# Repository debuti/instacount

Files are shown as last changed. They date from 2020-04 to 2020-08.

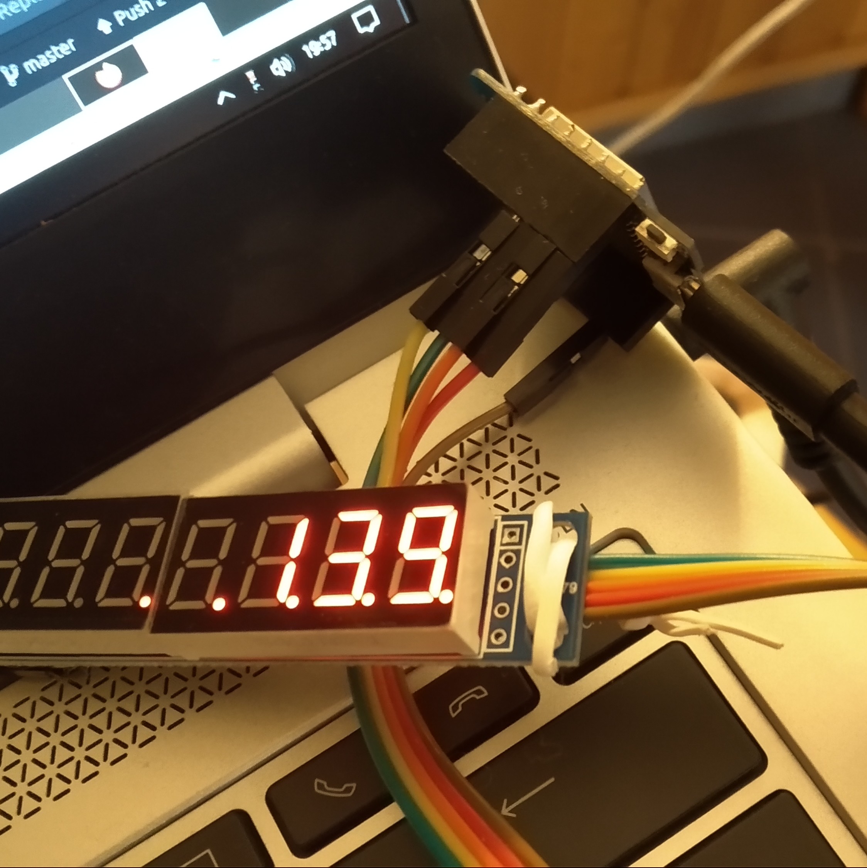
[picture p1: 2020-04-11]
IMG_20200409_195725.jpg

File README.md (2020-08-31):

# instacount

Sketch and hardware solution to display the followers count for any user

## Quick start
 * Connect to _instacount_ hotspot -> A captive portal for configuration will open
 * Insert your wifi details, the target Instagram account and your Instagram credentials. Adjust the other parameters to taste
 * Once saved the device will try to connect to the wifi network, if successful it will try to fetch the followers count using one of the provided Instagram credentials, if successful you are good to go, if not ..
 
## Troubleshooting
 * The device doesnt show anything on the display
   * Sometimes these chinese displays are unresponsive. Unplug and replug several times until the digits light up
 * The device never goes out of config
   * The wifi credentials are not correct, recheck them
 * The device always shows 0 followers
   * The Instagram credentials are not correct, recheck them. 
   * Try to use those credentials in a browser to see if they are challenged or banned by Instagram
 * The device shows 0 followers when powered-up
   * I'm working on this
 * When I reconfigure the device, the Instagram credentials are not persisted
   * They are, but they are not showed for security reasons! If the module is set to config mode without you knowing it, and your neighbour connects to the config page s/he will see your plain text password

## Description and usage
Polling updated display to show the count of followers of a given Instagram account.

Sadly, Instagram has no public API to retrieve the followers count for a given user. Because of that, instacount uses web scrapping methods to retrieve this information. Although it works, it is not the best solution as Instagram controls the number of requests made to its servers and can deny the access to resources for a given user. As of April 2020 the quota is 500 requests/user*day, meaning that a request can be made each 2.88 minutes

To overcome this limitation, instacount uses two concepts combined:
 * Poll more often at daytime and less often at night.
 * Use several accounts to be able to make requests as quick as possible.

Last, Instagram handles suspicious activities by issuing a challenge. If a given account is challenged, it wont be able to login and thus retrieve the count. To overcome this just login to the account from a web browser and response to the challenge. As instacount wont warn about this, to detect and be able to solve this, it is best to use your own accounts with instacount (and not dummy accounts)

## Features
 * Login based approach to enable a multi-account strategy
 * Configurable via wifi captive portal
 * Countdown until next request shown via display dots
 * Smart cooldown mechanism to temporarily disable the accounts that got too many requests
 * .dxf for case routing/printing also included!

## Hardware design
### BOM
 * ESP12E board
 * MAX7219 8-digit 8-segments module
 * Breakout board for ESP12E
 * 3,3V voltage regulator (remove the 0 Ohm resistor from the breakout board!)

### Connections
```
ESP12E GPIO13 to MAX7219 CLK
ESP12E GPIO12 to MAX7219 CS
ESP12E GPIO14 to MAX7219 DIN
```

## Build environment
 * PlatformIO: Quick-install with this *nosudo* oneliner `python3 -c "$(curl -fsSL https://raw.githubusercontent.com/platformio/platformio/develop/scripts/get-platformio.py)"; export PATH=$PATH:~/.platformio/penv/bin`

## Libraries
 * WifiManager
 * LedControl
 * DoubleResetDetector
 * ArduinoJSON

## Building
 * Go to the project folder and type `pio run` to build
 * Or `pio run -t upload` to upload

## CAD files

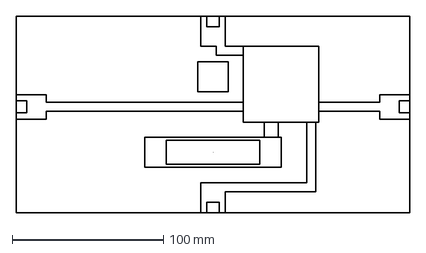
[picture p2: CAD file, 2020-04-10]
cam/instacount-panel-a.dxf
260.0 x 130.0 mm

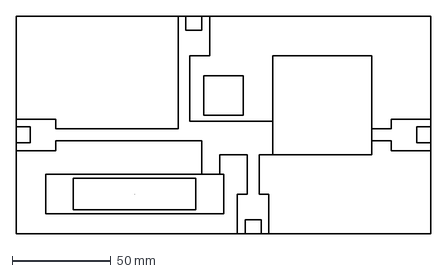
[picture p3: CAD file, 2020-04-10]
cam/instacount-panel-b.dxf
210.0 x 110.0 mm

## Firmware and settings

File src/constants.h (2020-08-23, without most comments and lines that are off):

#define DEBUG    true
#define LOG(str) if (DEBUG) Serial.println(str);
#define XSTR(s)	 STR(s)
#define STR(s)	 #s
#define DISPLAY_CLK						14
#define DISPLAY_LOAD					12
#define DISPLAY_DATA_IN				13
#define MAX7219_COUNT					1
#define DRD_TIMEOUT 					5						// Number of seconds after reset during which a subseqent reset will be considered a double reset. This sketch uses drd.stop() rather than relying on the timeout
#define DRD_ADDRESS						0						// RTC Memory Address for the DoubleResetDetector to use
#define INSTA_SCHEMA					"https://"
#define INSTA_HOST						"www.instagram.com"
#define BASE_PATH						  "/"
#define LOGIN_PATH						"/accounts/login/ajax/"
#define INSTA_PORT						443
#define INSTA_API_POSTFIX			"/?__a=1"
#define MAX_REQUESTS_DAY_PER_ACCOUNT	500
#define CHROME_WIN_UA 				"Mozilla/5.0 (Windows NT 10.0; WOW64) AppleWebKit/537.36 (KHTML, like Gecko) Chrome/67.0.3396.87 Safari/537.36"
#define STORIES_UA						"Instagram 123.0.0.21.114 (iPhone; CPU iPhone OS 11_4 like Mac OS X; en_US; en-US; scale=2.00; 750x1334) AppleWebKit/605.1.15"
#define COOLDOWN_MIN  				6*60*60*1000
#define COOLDOWN_INC  				3
#define DEFAULT_AP						"instacount"
#define DEFAULT_NIGHT_START		0
#define DEFAULT_NIGHT_END			8
#define DEFAULT_NIGHT_SPACING	3600
#define HTML_CSS_STYLES \
"<style>" \
".alert {" \
"  margin: 10px;" \
"  padding: 20px;" \
"  opacity: 1;" \
"  transition: opacity 0.6s;" \
"  margin-bottom: 15px;" \
"  font-family: -apple-system,BlinkMacSystemFont,\"Segoe UI\",Roboto,\"Helvetica Neue\",Arial,sans-serif,\"Apple Color Emoji\",\"Segoe UI Emoji\",\"Segoe UI Symbol\";" \
"  box-sizing: border-box;" \
"  border: 1px solid transparent;" \
"  border-radius: .25rem;" \
"  line-height: 1.5;" \
"}" \
".alert.info {" \
"  color: #004085;" \
"  background-color: #cce5ff;" \
"  border-color: #b8daff;" \
"}" \
".alert.light {" \
"  color: #818182;" \
"  background-color: #fefefe;" \
"  border-color: #fdfdfe;" \
"  margin: 2px;" \
"  padding: 2px;" \
"}" \
"</style>"
#define HTML_GLOBAL_HELP \
"<div class=\"alert info\">" \
"  <strong>Instacount instructions</strong>" \
"  <p>The configuration of instacount is made through a captive wifi portal. At first, since no configuration is yet made, instacount will expose the captive portal by default. Just connect to it and modify the parameters to fit your needs. If at some point you want to reconfigure instacount, just press the reset button twice, and the captive portal will show up again. Whenever the led stays on for 10 seconds or so after boot, and -conFiG- is shown in the display, the config portal will be on. Mind that if the configuration cannot be applied the captive portal will show up again.</p>" \
"  <p>Sadly, Instagram has no public API to retrieve the followers count for a given user. Because of that, instacount uses web scrapping methods to retrieve this information. Although it works, it is not the best solution as Instagram controls the number of requests made to its servers and can deny the access to resources for a given user. As of April 2020 the quota is 500 requests/user*day, meaning that a request can be made each 2.88 minutes</p>" \
"  <p>To overcome this limitation, instacount uses two concepts combined:" \
"    <ul>" \
"    <li>Poll more often at daytime and less often at night.</li>" \
"    <li>Use several accounts to be able to make requests as quick as possible.</li>" \
"    </ul>" \
"  </p>" \
"  <p>The display dots will be lightened in order to show the amount of time left until the next request.</p>" \
"  <p>Last, Instagram handles suspicious activities by issuing a challenge. If a given account is challenged, it wont be able to login and thus retrieve the count. To overcome this just login to the account from a web browser and response to the challenge. As instacount wont warn about this, to detect and be able to solve this, it is best to use your own accounts with instacount (and not dummy accounts)</p>" \
"</div>"
#define HTML_PROFILE_HELP\
"<div class=\"alert light\">" \
"  Insert the Instagram profile to be polled for followers count" \
"</div>"
#define HTML_ACCOUNTS_HELP\
"<div class=\"alert light\">" \
"  Insert at least one account/password. The format is: <br>" \
"  user1:passwd1;user2:passwd2;...<br>" \
"  Previously introduced credentials are not shown for security reasons. The field is limited to 100 characters." \
"</div>"
#define HTML_NIGHT_HELP\
"<div class=\"alert light\">" \
"  Insert the start and finish hours for the night, and the number of seconds you want instacount to wait between requests. <br>" \
"  Remember, the less usage at night means the more at day!" \
"</div>"
#define HTML_REQUESTS_HELP\
"<div class=\"alert light\">" \
"  This should be set to "XSTR(MAX_REQUESTS_DAY_PER_ACCOUNT)" but if you suffer a lot of cooldowns you'll probably need to decrease this value" \
"</div>"
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

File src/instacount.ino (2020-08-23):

#include "constants.h"

#include <ESP8266WiFi.h>
#include <WiFiClientSecure.h>
// Additional libraries needed by WiFiManager
#include <DNSServer.h>
//Local DNS Server used for redirecting all rs to the configuration portal
#include <ESP8266WebServer.h>
//Local WebServer used to serve the configuration portal


// To use this sketch in an ESP8266 board you have to follow the instructions at
// https://github.com/esp8266/Arduino#installing-with-boards-manager


#include <LedControl.h>
// To control an MAX7219 enabled display
// https://github.com/debuti/LedControl
// More advanced library based on wayoda's LedControl
// https://github.com/wayoda/LedControl

#include <DoubleResetDetector.h>
// For entering Config mode by pressing reset twice
// Available on the library manager (DoubleResetDetector)
// https://github.com/datacute/DoubleResetDetector

#include <ArduinoJson.h>
// Required for the YouTubeApi and used for the config file
// Available on the library manager (ArduinoJson)
// https://github.com/bblanchon/ArduinoJson

#include <WiFiManager.h>
// For configuring the Wifi credentials without re-programing
// Availalbe on library manager (WiFiManager)
// https://github.com/tzapu/WiFiManager

#include "FS.h"
// For storing configurations
// Already included in the include path by the esp8266 core
// https://arduino-esp8266.readthedocs.io/en/latest/filesystem.html


/** Typedefs **/
typedef struct {
  char* k;
  char* v;
} cookie_t;

typedef struct {
  char*         usr;
  char*         pwd;
  uint8_t       cookies_nb;
  cookie_t**    cookies;
  char*         csrftoken;
  unsigned long cooldown_until;
  unsigned long lasttry;
  unsigned long logins_nb;
  unsigned long ok_nb;
  unsigned long ko_nb;
} account_t;

typedef struct {
  uint8_t     start;
  uint8_t     end;
  uint16_t    spacing;
} night_t;

typedef struct {
  char*         profile;
  unsigned long max_requests_day_per_account;
  night_t       night;
  night_t       day;
  uint8_t       accounts_nb;
  account_t**   accounts;
} config_t;


/** Globals **/
WiFiClientSecure client;
DoubleResetDetector drd(DRD_TIMEOUT, DRD_ADDRESS);
LedControl lc = LedControl(DISPLAY_DATA_IN, DISPLAY_CLK, DISPLAY_LOAD, MAX7219_COUNT);

char ap[] = DEFAULT_AP;

const unsigned char caCert[] PROGMEM = DIGICERT_SHA2_HIGH_ASSURANCE_SERVER_CA;
const unsigned int caCertLen = (sizeof(caCert) / sizeof(caCert[0]));
const char* host PROGMEM = INSTA_HOST;
const int httpsPort = INSTA_PORT;
const char url_postfix[] PROGMEM = INSTA_API_POSTFIX;

bool shouldSaveConfig  = false;                         // flag for saving data
bool enteredConfigMode = false;                         // flag for state machine

unsigned long api_lasttime = 0;                         //last time api request has been done

config_t config = {
  .profile                      = NULL,
  .max_requests_day_per_account = MAX_REQUESTS_DAY_PER_ACCOUNT,
  .night = {
    .start                      = DEFAULT_NIGHT_START,
    .end                        = DEFAULT_NIGHT_END,
    .spacing                    = DEFAULT_NIGHT_SPACING
  },
  .day = {
    .start                      = DEFAULT_NIGHT_END,
    .end                        = DEFAULT_NIGHT_START,
    .spacing                    = 0
  },
  .accounts_nb                  = 0,
  .accounts                     = NULL
};



void printConfig(config_t* config) {
  Serial.println("config {");
  Serial.print("  profile : ");Serial.println(config->profile);
  Serial.print("  maxreqs : ");Serial.println(config->max_requests_day_per_account);
  Serial.println("  \t\tstart\tend\tspacing");
  Serial.print("  night :\t");Serial.print(config->night.start);Serial.print("\t");Serial.print(config->night.end);Serial.print("\t");Serial.println(config->night.spacing);
  Serial.print("  day :\t\t");Serial.print(config->day.start);Serial.print("\t");Serial.print(config->day.end);Serial.print("\t");Serial.println(config->day.spacing);
  Serial.print("  accounts[");Serial.print(config->accounts_nb);Serial.println("] {");
  for (int i=0; i<config->accounts_nb; i++) {
    Serial.println("    account {");
    {
      Serial.print("      usr/pwd :\t\t");Serial.print(config->accounts[i]->usr);Serial.print(":");
      for (int j=0; j<strlen(config->accounts[i]->pwd); j++) Serial.print('*');
      Serial.println();
    }
    Serial.print("      cool :\t\t");Serial.println(config->accounts[i]->cooldown_until);
    Serial.print("      lasttry :\t\t");Serial.println(config->accounts[i]->lasttry);
    {
      Serial.println("      logins_nb\tko_nb\tok_nb");
      Serial.print("      ");Serial.print(config->accounts[i]->logins_nb); Serial.print("\t\t");Serial.print(config->accounts[i]->ko_nb);Serial.print("\t");Serial.println(config->accounts[i]->ok_nb);
    }
    Serial.print("      csrftoken :\t");Serial.println((config->accounts[i]->csrftoken?config->accounts[i]->csrftoken:"NULL"));
    Serial.print("      cookies[");Serial.print(config->accounts[i]->cookies_nb);Serial.println("] {");
    for (int j=0; j<config->accounts[i]->cookies_nb; j++) {
      Serial.print("        ");Serial.print(config->accounts[i]->cookies[j]->k);Serial.print( " : ");Serial.println(config->accounts[i]->cookies[j]->v);
    }
    Serial.println("      }");
    Serial.println("    }");
  }
  Serial.println("  }");
  Serial.println("}");
}

/**
 * Frees the memory associated to the dynamic object
 **/
bool freeConfig(config_t* config) {
  free(config->profile);
  for (int idx = 0; idx < config->accounts_nb; idx++) {
    free(config->accounts[idx]->usr);
    free(config->accounts[idx]->pwd);
    free(config->accounts[idx]->csrftoken);
    for (int j=0; j<config->accounts[idx]->cookies_nb; j++) {
      free(config->accounts[idx]->cookies[j]->k);
      free(config->accounts[idx]->cookies[j]->v);
      free(config->accounts[idx]->cookies[j]);
    }
    free(config->accounts[idx]);
  }
  free(config->accounts);
}

/**
 * Checks if the config makes sense
 **/
bool checkConfig(config_t* config) {
  return ((strcmp(config->profile, "") > 0) && \
          (config->accounts_nb > 0) && \
          (config->accounts != NULL));
}

/**
 * Loads the configuration from storaged JSON into dynamic object
 **/
bool loadConfig(config_t* config) {
  File configFile = SPIFFS.open("/config.json", "r");
  if (!configFile) {
    Serial.println("Failed to open config file");
    return false;
  }

  size_t size = configFile.size();
  if (size > 1024) {
    Serial.println("Config file size is too large");
    return false;
  }

  StaticJsonDocument<500> json;
  DeserializationError err = deserializeJson(json, configFile);
  if (err) {
    Serial.println("Failed to parse config file");
    return false;
  }

  if (json["profile"]) config->profile = strdup(json["profile"]);
  if (json["max_requests_day_per_account"]) config->max_requests_day_per_account = json["max_requests_day_per_account"];
  if (json["accounts"]) {
    config->accounts = (account_t**)malloc(sizeof(account_t*)*json["accounts"].size());
    for (int idx = 0; idx < json["accounts"].size(); idx++) {
      config->accounts[idx] = (account_t*)malloc(sizeof(account_t));
      config->accounts[idx]->usr = strdup(json["accounts"][idx]["usr"]);
      config->accounts[idx]->pwd = strdup(json["accounts"][idx]["pwd"]);
      config->accounts[idx]->cookies_nb = 0;
      config->accounts[idx]->cookies = NULL;
      config->accounts[idx]->cooldown_until = 0;
      config->accounts[idx]->lasttry = 0;
      config->accounts[idx]->logins_nb = 0;
      config->accounts[idx]->ok_nb = 0;
      config->accounts[idx]->ko_nb = 0;
      config->accounts[idx]->csrftoken = NULL;
      config->accounts_nb++;
    }
  }
  if (json["night"]) {
    config->night.start = json["night"]["start"];
    config->night.end = json["night"]["end"];
    config->night.spacing = json["night"]["spacing"];
    unsigned long night_dur = 60*60*(config->night.end>config->night.start ?
                                      config->night.end-config->night.start :
                                      config->night.end-(config->night.start-24));
    unsigned long day_dur = 24*60*60-night_dur;
    config->day.start = json["night"]["end"];
    config->day.end = json["night"]["start"];
    config->day.spacing = day_dur/(config->max_requests_day_per_account*config->accounts_nb-night_dur/config->night.spacing);
    Serial.print("Day spacing: ");
    Serial.println(config->day.spacing);
  }
  Serial.println("Config loaded");
  return true;
}

/**
 *
 **/
bool saveConfig(WiFiManagerParameter* profileWMP,
                WiFiManagerParameter* max_requests_day_per_accountWMP,
                WiFiManagerParameter* accountsWMP,
                WiFiManagerParameter* night_startWMP,
                WiFiManagerParameter* night_endWMP,
                WiFiManagerParameter* night_spacingWMP) {
  StaticJsonDocument<500> json;
  json["profile"] = profileWMP->getValue();
  json["max_requests_day_per_account"] = max_requests_day_per_accountWMP->getValue();

  char *ptr;
  char* input = strdup(accountsWMP->getValue());
  char* freeme = input;
  JsonArray accounts = json["accounts"].to<JsonArray>();
  while ((ptr = strsep(&input, ";")) != NULL) {
    char* pwd = strstr((const char *)ptr, ":") + 1;
    char* usr = ptr;
    *(pwd - 1) = '\0';
    JsonObject nested = accounts.createNestedObject();
    nested["usr"] = usr;
    nested["pwd"] = pwd;
  }
  free(freeme);

  json["night"]["start"] = night_startWMP->getValue();
  json["night"]["end"] = night_endWMP->getValue();
  json["night"]["spacing"] = night_spacingWMP->getValue();

  /* Open and overwrite */
  File configFile = SPIFFS.open("/config.json", "w");
  if (!configFile) {
    Serial.println("Failed to open config file for writing");
    return false;
  }

  serializeJson(json, configFile);
  Serial.println("Saved JSON");
  return true;
}

/**
 * Callback when your device enters configuration mode on failed WiFi connection attempt
 **/
void configModeCallback (WiFiManager *myWiFiManager) {
  Serial.print("Entered config mode: ");
  Serial.println(WiFi.softAPIP());
  // We don't want the next time the board resets to be considered a double reset so we remove the flag
  drd.stop();
  enteredConfigMode = true;
}

/**
 * Callback notifying us of the need to save config
 **/
void saveConfigCallback () {
  shouldSaveConfig = true;
}

/**
 * Setup routine
 **/
void setup() {
  /* Start the UART */
  Serial.begin(115200);
  Serial.println("");
  Serial.print("Initializing. Free HEAP: ");
  Serial.print(ESP.getFreeHeap());
  Serial.print("/");
  Serial.print(ESP.getHeapFragmentation());
  Serial.print("/");
  Serial.println(ESP.getMaxFreeBlockSize());

  /* Start the display */
  lc.shutdown(0, false);
  lc.setIntensity(0, 8);
  lc.clearDisplay(0);

  /* Start the led */
  pinMode(LED_BUILTIN, OUTPUT);
  /* Turn the LED on (Note that LOW is the voltage level */
  digitalWrite(LED_BUILTIN, LOW);

  /* Start the storage */
  if (!SPIFFS.begin()) {
    Serial.println("Failed to mount FS");
    return;
  }
  /* Load configs from flash */
  loadConfig(&config);

  /* Start wifimanager */
  WiFiManager wifiManager;
  char tmp[10];
  wifiManager.setMinimumSignalQuality(10);
  wifiManager.setAPCallback(configModeCallback);
  wifiManager.setSaveConfigCallback(saveConfigCallback);

  wifiManager.setCustomHeadElement(HTML_CSS_STYLES);

  WiFiManagerParameter globalHelp(HTML_GLOBAL_HELP);
  wifiManager.addParameter(&globalHelp);

  WiFiManagerParameter profileWMP("profile", "Profile", config.profile, 50);  wifiManager.addParameter(&profileWMP);
  WiFiManagerParameter profileWMPHelp(HTML_PROFILE_HELP);  wifiManager.addParameter(&profileWMPHelp);
  WiFiManagerParameter accountsWMP("accounts", "Accounts", "", 100);  wifiManager.addParameter(&accountsWMP);
  WiFiManagerParameter accountsWMPHelp(HTML_ACCOUNTS_HELP);  wifiManager.addParameter(&accountsWMPHelp);
  snprintf(tmp, 10, "%d", config.night.start);
  WiFiManagerParameter night_startWMP("night_start", "Night starts at", tmp, 2);  wifiManager.addParameter(&night_startWMP);
  snprintf(tmp, 10, "%d", config.night.end);
  WiFiManagerParameter night_endWMP("night_end", "Night ends at", tmp, 2);  wifiManager.addParameter(&night_endWMP);
  snprintf(tmp, 10, "%d", config.night.spacing);
  WiFiManagerParameter night_spacingWMP("night_spacing", "Night spacing", tmp, 5);  wifiManager.addParameter(&night_spacingWMP);
  WiFiManagerParameter nightWMPHelp(HTML_NIGHT_HELP);  wifiManager.addParameter(&nightWMPHelp);
  snprintf(tmp, 10, "%d", config.max_requests_day_per_account);
  WiFiManagerParameter max_requests_day_per_accountWMP("max_requests_day_per_account", "Max requests per day and account", tmp, 10);  wifiManager.addParameter(&max_requests_day_per_accountWMP);
  WiFiManagerParameter max_requests_day_per_accountWMPHelp(HTML_REQUESTS_HELP);  wifiManager.addParameter(&max_requests_day_per_accountWMPHelp);

  lc.setString(0, "-conFiG-", 0);
  /** Check for double reset **/
  if (drd.detectDoubleReset()) {
    Serial.println("Double Reset Detected");
    wifiManager.startConfigPortal(ap, NULL);
  } else {
    Serial.println("No Double Reset Detected");
    wifiManager.autoConnect(ap, NULL);
  }

  /* Turn the LED off by making the voltage HIGH */
  digitalWrite(LED_BUILTIN, HIGH);

  /* Config must be saved afterwards as you have no access to the results from the callback */
  if (shouldSaveConfig && enteredConfigMode) {
    saveConfig(&profileWMP, &max_requests_day_per_accountWMP, &accountsWMP, &night_startWMP, &night_endWMP, &night_spacingWMP);
    freeConfig(&config);
    loadConfig(&config);
  }

  /* Force Config mode if the needed info is not in place */
  if (checkConfig(&config)) {
    Serial.println("");
    while (WiFi.status() != WL_CONNECTED) {
      delay(5);
      Serial.print(".");
    }
    Serial.println("");
    Serial.print("WiFi connected. IP address: ");
    Serial.println(WiFi.localIP());

    /* Synchronize time using SNTP. This is necessary to verify that the TLS certificates offered by the server are currently valid. */
    Serial.print("Setting time using SNTP. ");
    configTime(0, 0, "pool.ntp.org");
    setenv("TZ", "CET-1CEST,M3.5.0,M10.5.0/3", 0);  // Spain timezone
    delay(1000);
    time_t tnow = time(nullptr);
    Serial.print("Current time: ");
    Serial.print(ctime(&tnow));

    // Load root certificate in DER format into WiFiClientSecure object
    bool res = client.setCACert(caCert, caCertLen);
    if (!res) {
      Serial.println("Failed to load root CA certificate!");
      while (true) {
        yield();
      }
    }
  }
  else {
    /* The config mode is forced by not stopping the drd */
    Serial.println("Forcing Config Mode and resetting");
    WiFi.disconnect();
    delay(500);
    ESP.restart();
    delay(5000);
  }

  lc.setString(0, "        ", 0);
  drd.stop();
}

#define HANDLE_RETURN_CODE {                     \
  if (line.startsWith("HTTP/1.1 ")) {            \
    line.remove(0, strlen("HTTP/1.1 "));         \
    int end = line.indexOf(' ');                 \
    returncode = line.substring(0, end).toInt(); \
  }                                              \
}

//TODO: Dont use Strings here, just go and replace = and ; with \0 to access the values
#define HANDLE_SET_COOKIE {                                           \
  if (line.startsWith("Set-Cookie: ")) {                              \
    line.remove(0, strlen("Set-Cookie: "));                           \
    int sep = line.indexOf('=');                                      \
    int end = line.indexOf(';');                                      \
    String key = line.substring(0, sep);                              \
    String value = line.substring(sep+1, end);                        \
    if (key == "csrftoken") {                                         \
      free(account->csrftoken);                                       \
      account->csrftoken = strdup(value.c_str());                     \
    }                                                                 \
    bool found = false;                                               \
    for (int idx=0; idx<account->cookies_nb; idx++) {                 \
      if (key == account->cookies[idx]->k) {                          \
        free(account->cookies[idx]->v);                               \
        account->cookies[idx]->v=strdup(value.c_str());               \
        found = true;                                                 \
      }                                                               \
    }                                                                 \
    if (!found) {                                                     \
      account->cookies =                                              \
        (cookie_t**)realloc(account->cookies,                         \
                            sizeof(cookie_t*)*account->cookies_nb+1); \
      account->cookies[account->cookies_nb] =                         \
        (cookie_t*)malloc(sizeof(cookie_t));                          \
      account->cookies[account->cookies_nb]->k =                      \
        strdup(key.c_str());                                          \
      account->cookies[account->cookies_nb]->v =                      \
        strdup(value.c_str());                                        \
      account->cookies_nb++;                                          \
    }                                                                 \
  }                                                                   \
}

void logout(account_t* account) {
  /* Delete all the cookies! */
  while (account->cookies_nb) {
    account->cookies_nb--;
    free(account->cookies[account->cookies_nb]->k);
    free(account->cookies[account->cookies_nb]->v);
    free(account->cookies[account->cookies_nb]);
    account->cookies = (cookie_t**)realloc(account->cookies, sizeof(cookie_t*)*account->cookies_nb);
  }
}

bool getCSRF(account_t* account) {
  Serial.print("Getting CSRF for ");
  Serial.print(host);

  /* Connect to remote server */
  if (!client.connect(host, httpsPort)) {
    Serial.println("connection failed");
    return false;
  }

  /* Verify validity of server's certificate */
  if (!client.verifyCertChain(host)) {
    Serial.println("certificate verification failed!");
    return false;
  }

  /* Get the initial cookies */
  client.print("GET / HTTP/1.1\r\n");
  client.print("Host: ");client.print(host);client.print("\r\n");
  client.print("User-Agent: ");client.print(STORIES_UA);client.print("\r\n");
  client.print("Connection: close\r\n\r\n");

  long returncode = 0;
  while (client.connected() || client.available()) {
   if (client.available()) {
    String line = client.readStringUntil('\n');
    LOG(line)
    HANDLE_RETURN_CODE
    HANDLE_SET_COOKIE
    if (line.equals("\r")) break;
   }
  }

  Serial.print(" -> ");Serial.println(returncode);
  return (returncode == 200);
}
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
void loop() {
  bool night = false;
  time_t tnow = time(nullptr);
  struct tm *tnowr = gmtime(&tnow);
  uint8_t percent = 0;
  uint8_t progress = 0;
  account_t* account;
  long result;

  if (config.night.start < config.night.end) {
    if (config.night.start <= tnowr->tm_hour and tnowr->tm_hour < config.night.end) night = true;
  }
  else {
    if (config.night.start <= tnowr->tm_hour or tnowr->tm_hour < config.night.end) night = true;
  }

  if ((night && millis() - api_lasttime > config.night.spacing * 1000) ||
      (!night && millis() - api_lasttime > config.day.spacing * 1000)){
    Serial.println("---");
    api_lasttime = millis();
    Serial.print("Free HEAP: ");
    Serial.print(ESP.getFreeHeap());
    Serial.print("/");
    Serial.print(ESP.getHeapFragmentation());
    Serial.print("/");
    Serial.println(ESP.getMaxFreeBlockSize());
    Serial.print("Date: ");
    Serial.print(ctime(&tnow));

    if ((account = doOrGetLogin(selectAccount())) != NULL)
      if ((result = followersCount(account)) > 0)
        count = result;

    printConfig(&config);

    Serial.println("---");
  }

  percent = (millis() - api_lasttime)*100 / (1000 * (night ? config.night.spacing : config.day.spacing));
  progress = (percent < 100/9 ? 0b11111111 :
              (percent < 200/9 ? 0b01111111 :
               (percent < 300/9 ? 0b00111111 :
                (percent < 400/9 ? 0b00011111 :
                 (percent < 500/9 ? 0b00001111 :
                  (percent < 600/9 ? 0b00000111 :
                   (percent < 700/9 ? 0b00000011 :
                    (percent < 800/9 ? 0b00000001 : 0b00000000))))))));
  lc.setNumber(0, count, progress);
}

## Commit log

2020-04-10 Added CAM models
    [instacount-panel-a.dxf, instacount-panel-b.dxf]
2020-08-23 Added Makefile. Removed softAP pwd. Fixed bug with PROGMEM
    [constants.h, instacount.ino]
